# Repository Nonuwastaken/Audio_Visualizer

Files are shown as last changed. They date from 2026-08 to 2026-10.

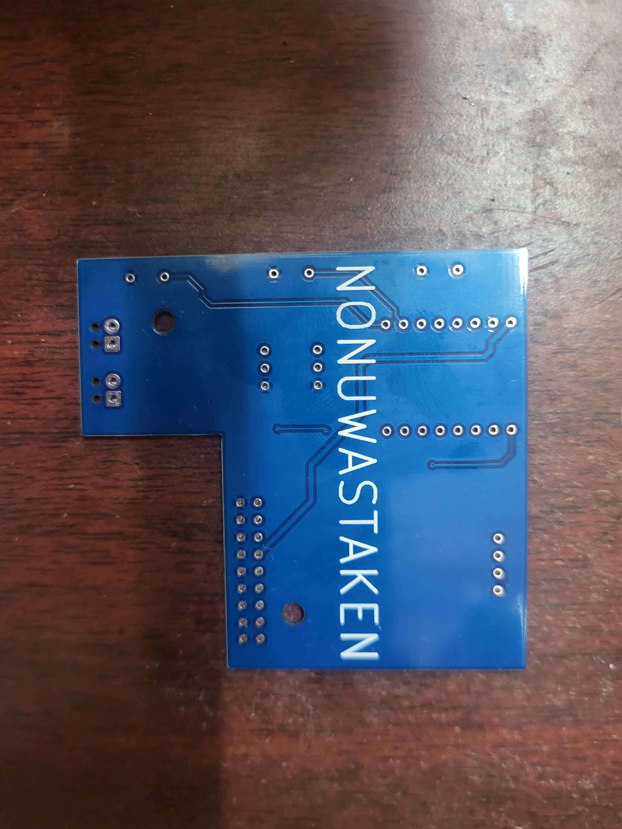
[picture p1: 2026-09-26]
Custom_PCB/20260926_110044.jpg

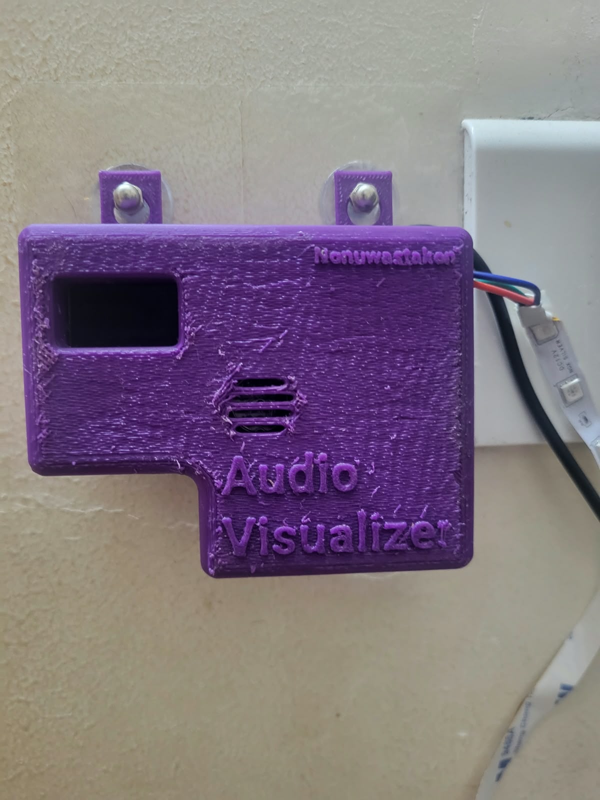
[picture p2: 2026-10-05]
Final_Look/Enclosure.jpeg

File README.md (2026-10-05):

# Audio Visualizer

Compact ESP32-C3 audio visualizer — captures sound via an I2S microphone, displays live levels on an OLED, and drives an RGB LED strip through MOSFET channels for real-time audio-reactive lighting. 

## Overview

The system listens to ambient/line audio through an I2S MEMS microphone, computes amplitude in real time on the ESP32-C3, and maps it to:

- An OLED readout of live audio levels
- RGB LED strip brightness/color, switched via high-power MOSFET modules (one channel per color)

## Hardware

Built around an ESP32-C3, an INMP441 I2S microphone, a 0.96" I2C OLED, and an RGB LED strip driven through XY-MOS MOSFET modules. Full component list and costs are linked below.

### Pin Assignments

- **XY-MOS (R/G/B channels):** GPIO 0 / 1 / 3
- **INMP441 (I2S mic):** SCK = GPIO 4, WS = GPIO 5, SD = GPIO 6
- **SSD1306 OLED (I2C):** SDA = GPIO 21, SCL = GPIO 20

## Tuning Sensitivity

You can adjust how the visualizer reacts by editing these parameters at the top of each sketch:

```cpp
// 1. VOLUME THRESHOLDS
#define NOISE_FLOOR     5000
#define MAX_LOUDNESS    13500

// 2. FADING SPEEDS (0.01 to 1.0)
#define FADE_UP_SPEED   1.0   // Higher = snappier reaction to loud beats
#define FADE_DOWN_SPEED 0.1   // Lower = slower, smoother fade out between beats
```

| Parameter | What it does | Tune it if... |
|---|---|---|
| `NOISE_FLOOR` | Amplitude below this is treated as silence (LEDs off) | LEDs flicker in a quiet room → raise it. Lights don't react to soft sounds → lower it |
| `MAX_LOUDNESS` | Amplitude at which the LEDs hit full brightness | LEDs are always maxed out → raise it. Never get bright enough → lower it |
| `FADE_UP_SPEED` | How fast brightness rises with sound (0.01–1.0) | Want a snappier reaction to beats → raise it |
| `FADE_DOWN_SPEED` | How fast brightness falls after a sound (0.01–1.0) | Want a smoother, slower fade-out → lower it |

The ideal values depend on your microphone, its placement, and the room, so tune them to your setup. A good approach is to start with `NOISE_FLOOR` just above your quiet-room baseline, then adjust `MAX_LOUDNESS` until the lights peak on your loudest sounds.

## Code Variants

Several sketches are included, each driving the RGB strip differently while sharing the same I2S/OLED core:

| Sketch | Behavior |
|---|---|
| `multi_colour_audio.ino` | Audio-reactive brightness with a slow, continuously shifting hue cycle across R/G/B |
| `red_audio.ino` | Audio-reactive brightness, fixed red |
| `green_audio.ino` | Audio-reactive brightness, fixed green |
| `blue_audio.ino` | Audio-reactive brightness, fixed blue |
| `cyan_audio.ino` | Audio-reactive brightness, fixed cyan |
| `purple_audio.ino` | Audio-reactive brightness, fixed purple |
| `yellow_audio.ino` | Audio-reactive brightness, fixed yellow |
| `white_audio.ino` | Audio-reactive brightness, fixed white (all channels) |

## Circuit Diagram

https://app.cirkitdesigner.com/project/735b4f31-fd71-42aa-8f38-7ad56208304c

## PCB & Enclosure

- **PCB:** The custom V2 PCB design files are available in the `Custom_PCB` folder.
- **Enclosure (CAD):** A custom enclosure was designed for the V2 board. The source CAD files are available in the `CAD Model` folder.

**Onshape CAD:**  
https://cad.onshape.com/documents/6593946ba04cc1c559037129/w/a2d187fac915f00b7de97ec5/e/4e3bb7f6afe98f245e745010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

> **Note:** If you encounter a 403 Forbidden error, copy the link and open it in a new tab.

> [!IMPORTANT]
> **Manual wiring required!** The PCB does not connect everything for you:
>
> 1. **Wire GND and VIN- of the MOSFET modules** by hand with a wire.
> 2. **Screw the LED strip wires** into the screw terminals on the MOSFET modules/PCB according to the circuit diagram given.
>
> Skip these and the LED strip won't light up.

### PCB Mounting Holes

The PCB mounting holes in the CAD model are sized for **M3 heat-set inserts**. If you're using something different, adjust the hole size in the CAD model:

- **Other bolt/insert sizes:** change the hole diameter to match your hardware.
- **Screwing directly into the plastic (no inserts):** set the hole diameter to **2.9-3 mm** (For M3).

## Component List

- V1: https://docs.google.com/spreadsheets/d/1ALqold5_36gFdbRfQ2sbJwHor0Tc50hgfMq46gXfjWg/edit?usp=sharing
- V2: https://docs.google.com/spreadsheets/d/10Zfk7NXO29kVGQfq_vPPTgnpW9qup-5_QyMn6JiCvyc/edit?usp=sharing

## Status

- **V1:** complete and functional, built on perfboard with screw-terminal connections.
- **V2:** complete. The perfboard/screw-terminal wiring has been replaced with a custom PCB, and a custom enclosure has been designed to house it, making the project easier to replicate and more robust.

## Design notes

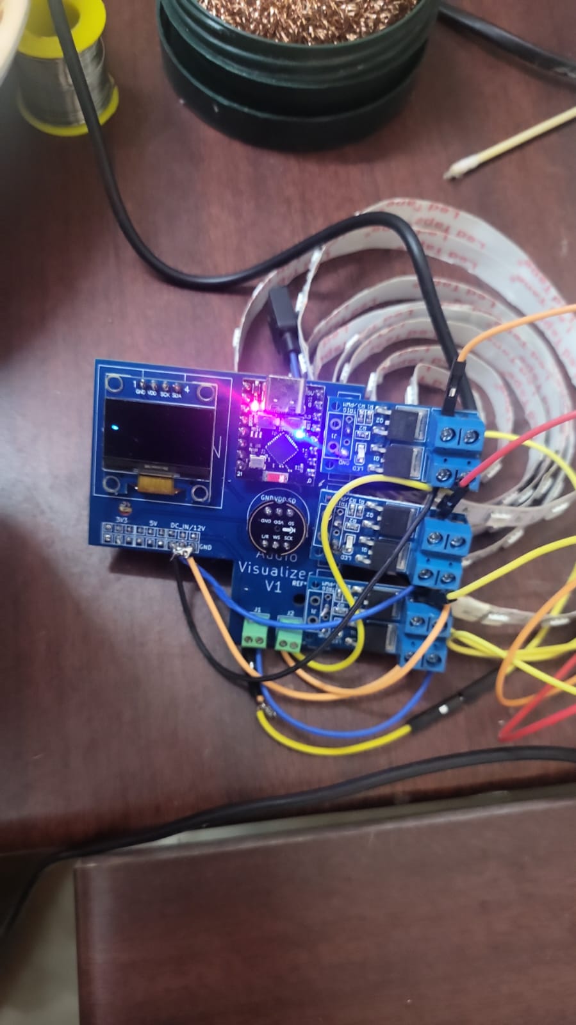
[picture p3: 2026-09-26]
Custom_PCB/IMG-20260907-WA0013.jpg

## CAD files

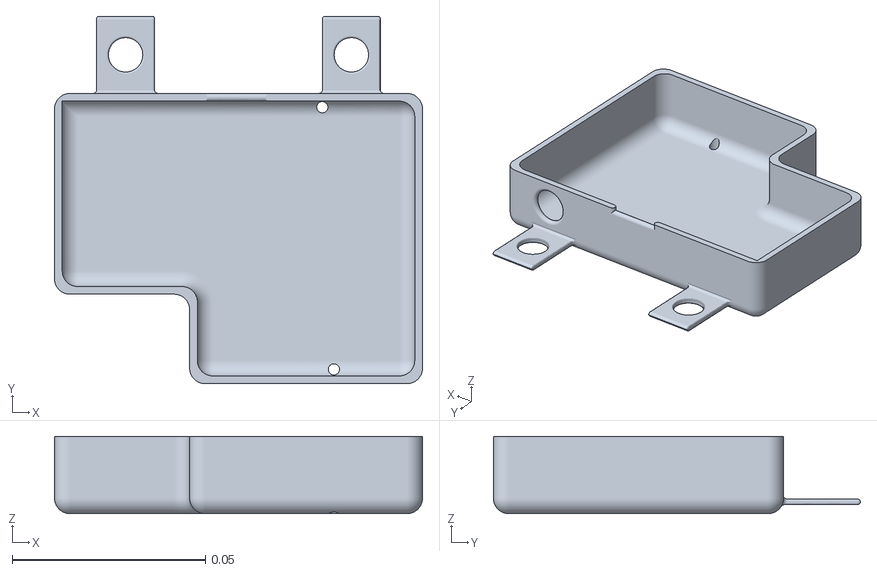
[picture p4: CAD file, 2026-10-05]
CAD Model/Case_Back.stl
0.0953 x 0.0951 x 0.02

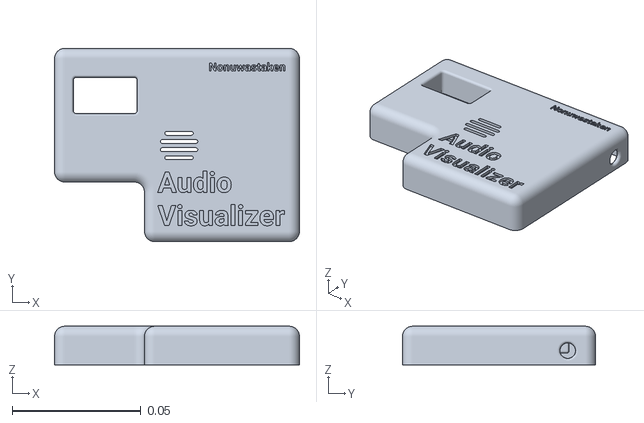
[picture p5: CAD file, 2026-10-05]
CAD Model/Case_Front.stl
0.0953 x 0.0752 x 0.015

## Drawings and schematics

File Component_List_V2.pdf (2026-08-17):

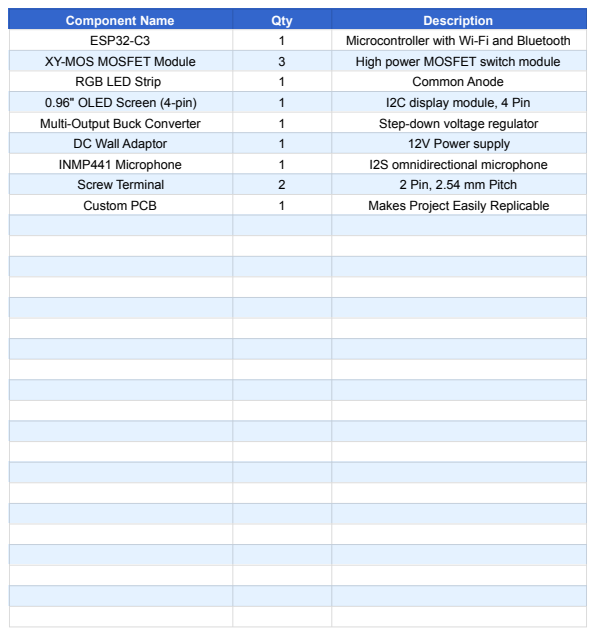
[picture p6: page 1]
Component Name; Qty; Description; ESP32-C3; Microcontroller with Wi-Fi and Bluetooth; XY-MOS MOSFET Module; High power MOSFET switch module; RGB LED Strip; Common Anode; 0.96" OLED Screen (4-pin); I2C display module, 4 Pin; Multi-Output Buck Converter; Step-down voltage regulator; DC Wall Adaptor; 12V Power supply; INMP441 Microphone; I2S omnidirectional microphone; Screw Terminal; 2 Pin, 2.54 mm Pitch; Custom PCB; Makes Project Easily Replicable

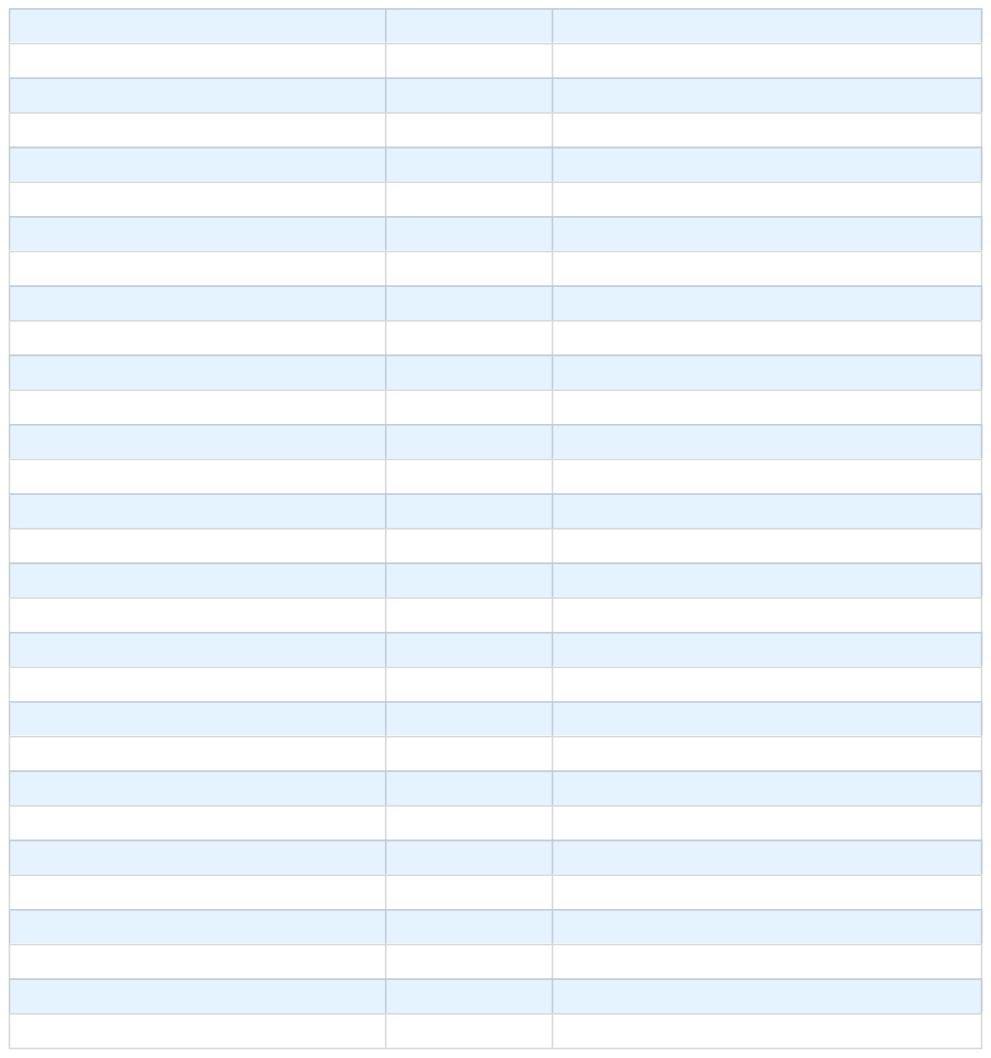
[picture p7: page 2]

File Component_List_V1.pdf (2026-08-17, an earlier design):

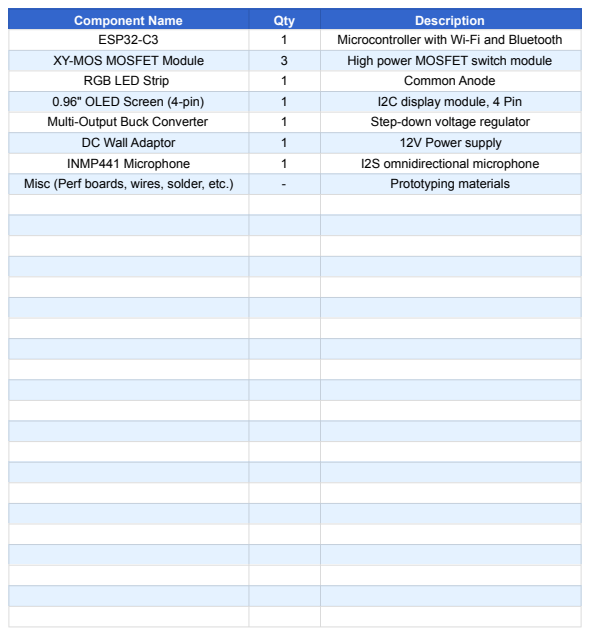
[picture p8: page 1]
Component Name; Qty; Description; ESP32-C3; Microcontroller with Wi-Fi and Bluetooth; XY-MOS MOSFET Module; High power MOSFET switch module; RGB LED Strip; Common Anode; 0.96" OLED Screen (4-pin); I2C display module, 4 Pin; Multi-Output Buck Converter; Step-down voltage regulator; DC Wall Adaptor; 12V Power supply; INMP441 Microphone; I2S omnidirectional microphone; Misc (Perf boards, wires, solder, etc.); Prototyping materials

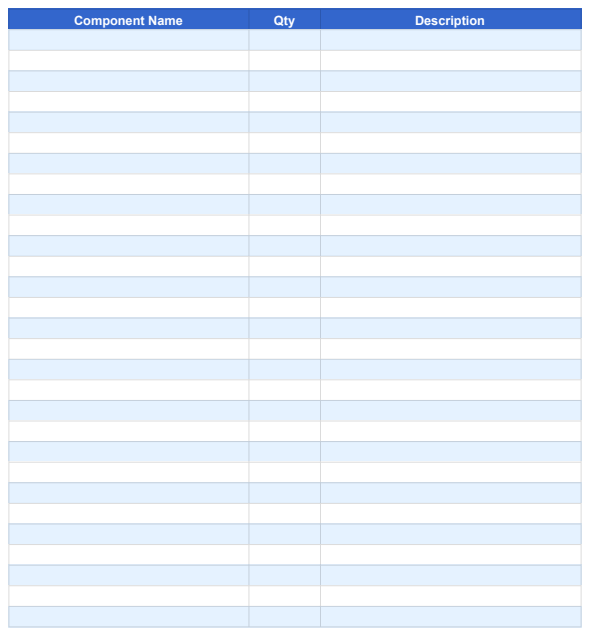
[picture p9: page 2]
Component Name; Qty; Description

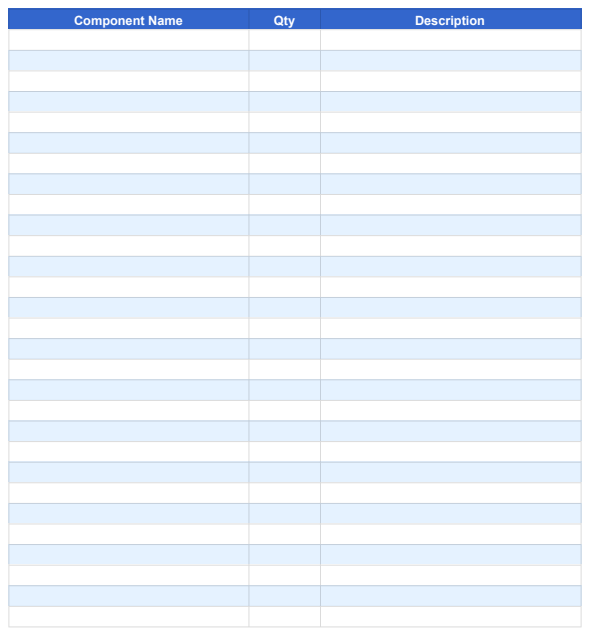
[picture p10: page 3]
Component Name; Qty; Description

Component Name | Qty | Description

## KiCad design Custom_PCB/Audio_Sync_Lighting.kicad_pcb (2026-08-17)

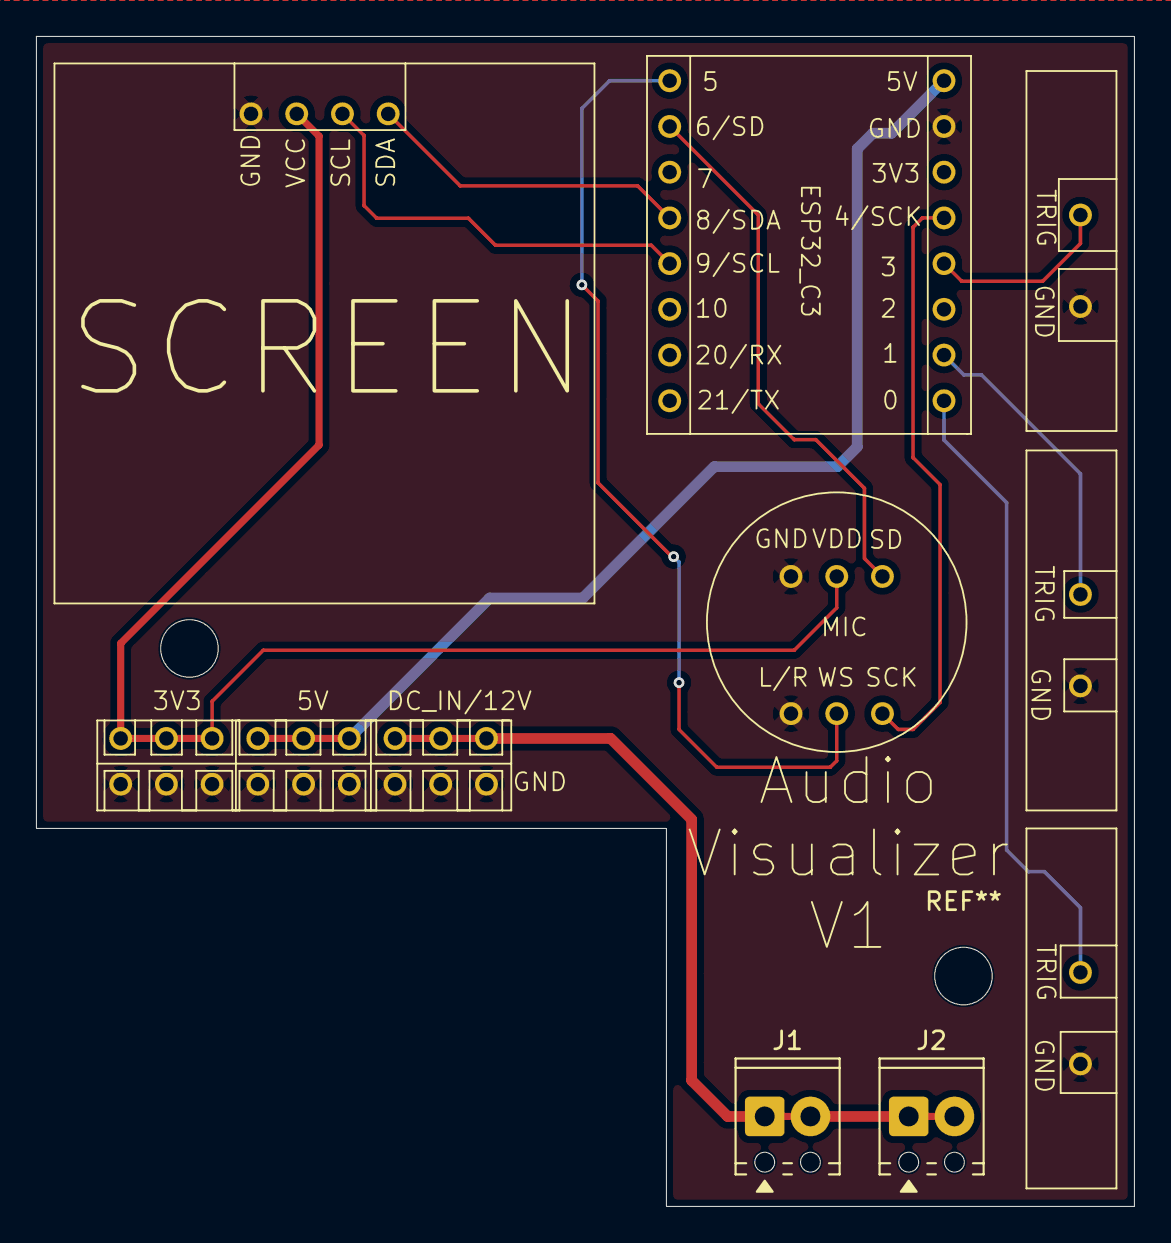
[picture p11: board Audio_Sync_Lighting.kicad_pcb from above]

Board: 2 copper layers, 61.0 x 65.0 mm, 9 parts (0 on the bottom side), 12 nets.

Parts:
J1, J2: Screw_Terminal_01x02; TerminalBlock_Phoenix_MPT-0,5-2-2.54_1x02_P2.54mm_Horizontal
U1: ESP32_C3; ESP32_C3_SuperMini
U2: 0.96_OLED
U3: Microphone; INMP441_Microphone
U4, U5, U8: XY_MOS
U7: Buck; Buck_Multi_Output

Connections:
+3.3V: U2.2 (3V3), U3.5 (VDD), U7.3 (3V3)
+5V: U1.9 (5V), U7.1 (5V)
GND: U1.10 (GND), U2.1 (GND), U3.1 (L/R), U3.4 (GND), U4.1 (GND), U5.1 (GND), U7.2 (GND), U8.1 (GND)
unnamed: J1.1, J1.2, J2.1, J2.2, U7.4 (DC_IN)
unnamed: U1.16 (0), U8.2 (TRIG)
unnamed: U1.15 (1), U5.2 (TRIG)
unnamed: U1.13 (3), U4.2 (TRIG)
unnamed: U1.12 (4/SCK), U3.3 (SCK)
unnamed: U1.1 (5), U3.2 (WS)
unnamed: U1.2 (6/SD), U3.6 (SD)
unnamed: U1.4 (8/SDA), U2.4 (SDA)
unnamed: U1.5 (9/SCL), U2.3 (SCK)

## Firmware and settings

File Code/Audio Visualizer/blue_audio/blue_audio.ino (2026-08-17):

#include <driver/i2s.h>
#include <Wire.h>
#include <Adafruit_GFX.h>
#include <Adafruit_SSD1306.h>

// --- RGB MOSFET PINS ---
#define RED_PIN   1
#define GREEN_PIN 3
#define BLUE_PIN  0

// --- I2S MICROPHONE PINS ---
#define I2S_WS    5
#define I2S_SCK   4
#define I2S_SD    6
#define I2S_PORT  I2S_NUM_0

// --- OLED ---
#define SCREEN_WIDTH 128
#define SCREEN_HEIGHT 64
#define OLED_RESET -1
#define SDA_PIN 21
#define SCL_PIN 20

Adafruit_SSD1306 display(SCREEN_WIDTH, SCREEN_HEIGHT, &Wire, OLED_RESET);
bool oledFound = false;
uint8_t waveBuffer[SCREEN_WIDTH] = {0};

// ==========================================
// --- TWEAK THESE VARIABLES TO FINE-TUNE ---
// ==========================================

// 1. VOLUME THRESHOLDS (Scaled down numbers)
#define NOISE_FLOOR     5000   // Ignore sounds quieter than this
#define MAX_LOUDNESS    100000  // Hits max brightness at this volume

// 2. FADING SPEEDS (0.01 to 1.0)
#define FADE_UP_SPEED   1.0  // Higher = Snappier reaction to loud beats
#define FADE_DOWN_SPEED 0.1 // Lower = Slower, smoother fade out between beats

// ==========================================

float smoothBrightness = 0;

void setupI2S() {
  const i2s_config_t i2s_config = {
    .mode = i2s_mode_t(I2S_MODE_MASTER | I2S_MODE_RX),
    .sample_rate = 16000,
    .bits_per_sample = I2S_BITS_PER_SAMPLE_32BIT,
    .channel_format = I2S_CHANNEL_FMT_ONLY_LEFT,
    .communication_format = I2S_COMM_FORMAT_STAND_I2S,
    .intr_alloc_flags = ESP_INTR_FLAG_LEVEL1,
    .dma_buf_count = 8,
    .dma_buf_len = 64,
    .use_apll = false
  };
  const i2s_pin_config_t pin_config = {
    .mck_io_num = I2S_PIN_NO_CHANGE, 
    .bck_io_num = I2S_SCK,
    .ws_io_num = I2S_WS,
    .data_out_num = I2S_PIN_NO_CHANGE,
    .data_in_num = I2S_SD
  };
  i2s_driver_install(I2S_PORT, &i2s_config, 0, NULL);
  i2s_set_pin(I2S_PORT, &pin_config);
  i2s_start(I2S_PORT);
}

void setup() {
  Serial.begin(115200);

  pinMode(RED_PIN, OUTPUT);
  pinMode(GREEN_PIN, OUTPUT);
  pinMode(BLUE_PIN, OUTPUT);
  
  analogWrite(RED_PIN, 0);
  analogWrite(GREEN_PIN, 0);
  analogWrite(BLUE_PIN, 0);

  Wire.begin(SDA_PIN, SCL_PIN);
  if (!display.begin(SSD1306_SWITCHCAPVCC, 0x3C)) {
    Serial.println("SSD1306 not found!");
    oledFound = false;
  } else {
    oledFound = true;
    display.clearDisplay();
    display.display();
  }

  setupI2S();
  Serial.println("Audio Visualizer Ready!");
}

#define OLED_REFRESH_EVERY 3
int loopCount = 0;

void loop() {
  size_t bytesIn = 0;
  int32_t samples[64];

  esp_err_t result = i2s_read(I2S_PORT, &samples, sizeof(samples), &bytesIn, portMAX_DELAY);

  if (result == ESP_OK && bytesIn > 0) {
    int samplesRead = bytesIn / sizeof(int32_t);
    int32_t maxAmplitude = 0;

    for (int i = 0; i < samplesRead; i++) {
      int32_t raw = samples[i];
      
      // Scale down those massive 32-bit values by shifting bits
      raw >>= 14; 
      
      if (abs(raw) > maxAmplitude) {
        maxAmplitude = abs(raw);
      }
    }

    // Print the scaled down number so you can check your room's baseline
    Serial.print("Scaled Mic Value: ");
    Serial.println(maxAmplitude);

    // Calculate the target brightness based on your thresholds
    int targetBrightness = 0;
    if (maxAmplitude > NOISE_FLOOR) {
      targetBrightness = map(maxAmplitude, NOISE_FLOOR, MAX_LOUDNESS, 0, 255);
      targetBrightness = constrain(targetBrightness, 0, 255);
    }

    // Apply the gradual fading logic
    if (targetBrightness > smoothBrightness) {
      smoothBrightness += (targetBrightness - smoothBrightness) * FADE_UP_SPEED;
    } else {
      smoothBrightness += (targetBrightness - smoothBrightness) * FADE_DOWN_SPEED;
    }
    
    // Prevent floating point errors from dropping it below zero
    if (smoothBrightness < 1.0) smoothBrightness = 0;
    
    int brightness = (int)smoothBrightness;

    // Output to Blue LED only
    analogWrite(GREEN_PIN, brightness);
    analogWrite(BLUE_PIN, 0);
    analogWrite(RED_PIN, 0);

    // Update the OLED display
    if (oledFound) {
      loopCount++;
      if (loopCount >= OLED_REFRESH_EVERY) {
        loopCount = 0;
        memmove(waveBuffer, waveBuffer + 1, SCREEN_WIDTH - 1);
        waveBuffer[SCREEN_WIDTH - 1] = map(brightness, 0, 255, 0, SCREEN_HEIGHT - 1);

        display.clearDisplay();
        for (int x = 0; x < SCREEN_WIDTH; x++) {
          int barHeight = waveBuffer[x];
          int y = (SCREEN_HEIGHT - barHeight) / 2;
          display.drawFastVLine(x, y, barHeight, SSD1306_WHITE);
        }
        display.display();
      }
    }
  }
}
